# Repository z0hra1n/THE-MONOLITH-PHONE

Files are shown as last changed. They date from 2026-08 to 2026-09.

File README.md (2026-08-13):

# MONOLITH
bVXsz1786632561

Ahh, i finally get to yap about it.
This is MONOLITH. a phone, a brick , a portable computer, but most importantly, a MONOLITH.
The reason im calling it a monolith cuz its literally gonna be built like a shiny MONOLITH. especially because its outer body is inteded to be made from aluminum which acts as a passive heat sink and looks pretty cool.The design was heavily inspired by Nothing and Apple.

The pcb is quite complicated, and the design is pretty human.It was not easy to make as i am only 15, this is my second pcb, the schematic itself was very hard.The pcb ws harder.I got help from reddit and tomachie.com with the schematic so it was pretty easy to disagnose.But, when it came to me m,aking the pcb, after i was done connecting everything, the drc gave 2000 violations.I was scared, but turns out most of those were easy fixable in one or two clicks.I also did not keep in mind the manufacturing constraints, so i fixed the values, and most of the errors were gone.I was pleased.






Finally, i made the enclosure very minimalist and functional.The back has a plastic went to let out the rf and wifi/bt signals.
the rear camera physically rotates to become the selfie camera.



The specs are pretty nuts.It has the radxa nx5 16 gb ram and 256 emms variant.An oled with 120hz refresh rate, and a batter of about 120000 mah.Im not sure itll last much without optimisation tho.

Yeah! i hope it overtakes apple!

| Purpose | Component / Item | Qty | Cost (USD) | Distributor | Part Number |
|---|---|----:|---:|---|---|
| Decoupling | 10µF 25V X5R 0603 Capacitor | 10 | $1.46 | Digi-Key | GRM188R61E106MA73J |
| Bulk Decoupling | 22µF 16V 0603 Capacitor | 12 | $4.44 | Digi-Key | GMC10X5R226M16NTCT |
| Power Filtering | 1µF 25V X7R 0603 Capacitor | 10 | $0.52 | Digi-Key | TMK107B7105KA-T |
| Signal Filtering | 10nF 100V X7R Capacitor | 5 | $0.48 | Digi-Key | GCM188R72A103KA37D |
| Signal Filtering | 47nF 50V X7R Capacitor | 5 | $1.00 | Digi-Key | GCM188R71H473KA55D |
| Decoupling | 100nF 50V Y5V Capacitor | 5 | $0.48 | Digi-Key | CC0603ZRY5V9BB104 |
| Crystal Load | 18pF C0G Capacitor | 5 | $1.29 | Digi-Key | QSCP251Q180J1GV001T |
| Power Filtering | 4.7µF 25V X5R Capacitor | 5 | $1.15 | Digi-Key | GRM188R61E475KE11D |
| Pull-ups / General | 10kΩ 1% Resistor | 15 | $0.46 | Digi-Key | CRCW060310K0FKEA |
| Voltage Divider | 47kΩ 1% Resistor | 5 | $0.48 | Digi-Key | RC0603FR-0747KL |
| Feedback Divider | 255kΩ 1% Resistor | 5 | $0.48 | Digi-Key | ERJ-3EKF2553V |
| Feedback Divider | 180kΩ 5% Resistor | 5 | $0.48 | Digi-Key | RC0603JR-07180KL |
| Feedback Divider | 56kΩ 1% Resistor | 5 | $0.48 | Digi-Key | ERJ-3EKF5602V |
| Pull-ups | 2.2kΩ 1% Resistor | 10 | $0.24 | Digi-Key | RC0603FR-072K2L |
| USB Configuration | 5.1kΩ 1% Resistor | 5 | $0.53 | Digi-Key | RC0603FR-075K1L |
| Precision Divider | 29.8kΩ 0.1% Resistor | 5 | $0.53 | Digi-Key | RT0603BRD0729K8L |
| General Purpose | 12kΩ 1% Resistor | 5 | $0.48 | Digi-Key | RC0603FR-0712KL |
| Feedback Divider | 240kΩ 5% Resistor | 5 | $0.48 | Digi-Key | ERJ-3GEYJ244V |
| General Purpose | 1kΩ 1% Resistor | 5 | $0.48 | Digi-Key | CRCW06031K00FKEA |
| Compute Module Interface | 260-pin SODIMM Socket | 2 | $3.50 | Digi-Key | 2309407-1 |
| Display Interface | 22-pin FFC Connector | 2 | $4.91 | Digi-Key | FH12-22S-0.5SH(55) |
| Display Output | Micro HDMI Receptacle | 2 | $3.94 | Digi-Key | 0467651301 |
| USB Connectivity | USB Type-C Receptacle | 2 | $0.61 | Digi-Key | USB4970-00-A |
| Battery Charging | BQ25895 Li-Ion Charger IC | 2 | $6.42 | Digi-Key | BQ25895RTWR |
| Audio Output | SSM2518 Class-D Amplifier | 1 | $7.18 | Digi-Key | SSM2518CPZ |
| Input Protection | 6V TVS Diode | 2 | $0.92 | Digi-Key | SMAJ6.0CA |
| 5V Power Rail | TPS61088 10A Boost Converter | 2 | $5.24 | Digi-Key | TPS61088RHLR |
| USB Protection | USB ESD Protection IC | 5 | $5.64 | Digi-Key | TPD2EUSB30DRTR |
| RF Connection | U.FL (MHF1) Coax Cable | 1 | $2.04 | Digi-Key | CA-DKCA1-100L1-I0I0 |
| USB Expansion | USB2512B 2-Port USB Hub | 2 | $3.36 | Digi-Key | USB2512B-AEZG |
| Motion Sensing | BMI270 IMU | 1 | $4.04 | Digi-Key | BMI270 |
| Clock Source | 24MHz Crystal | 2 | $0.99 | Digi-Key | 535-10643-1 |
| User Input | Tactile Push Button | 5 | $1.82 | Digi-Key | SWT0005-015516SSAC |
| Power Stage | 2.2µH 15A Inductor | 2 | $2.81 | Digi-Key | MWSA1205S-2R2MT |
| Power Stage | 1µH 10A Inductor | 2 | $4.41 | Digi-Key | 74437349010 |
| 1.8V Rail | AP2112K 1.8V LDO | 2 | $0.52 | Digi-Key | AP2112K-1.8TRG1 |
| 3.3V Rail | TLV75533 3.3V LDO | 2 | $0.59 | Digi-Key | TLV75533PDQNR |
| Cellular Connectivity | LTE FPC Antenna | 1 | $2.81 | Digi-Key | AANI-FB-0173 |
| Display Cable | Micro HDMI to Mini HDMI Cable | 1 | $4.68 | Digi-Key | FIT0649 |
| USB Accessories | USB-A to Micro USB Cable | 2 | $3.02 | Digi-Key | DH-20M50055 |
| USB Accessories | USB-C to USB-C Cable | 1 | $4.46 | Digi-Key | 10165794-Z0100YBLF |
| Additional Decoupling | 100nF X7R Capacitor | 10 | $0.67 | Digi-Key | C0603C104K3RACTU |
| Thermal Management | Heat Sink Thermal Sticker | 1 | $1.43 | Digi-Key | 6308 |
| Assembly | Kapton Tape (10mm) | 1 | $2.78 | Digi-Key | KAPTON-TAPE10MM |
| Temperature Monitoring | 10kΩ NTC Thermistor | 2 | $1.88 | Digi-Key | B57861S0103F040 |
| Camera | 12MP IMX477P Camera Module | 1 | $59.99 | Arducam | B0517 |
| Miscellaneous | Batteries, BLE Module, Connectors | 4 | $290.47 | AliExpress | Various |
| PCB Manufacturing | PCB Fabrication + Engineering | 1 | $72.96 | PCB Fab | — |
| Portable Power | 20,000mAh Power Bank | 1 | $30.29 | Amazon | Duracell |
| Enclosure | CNC Aluminium Enclosure (Estimate) | 1 | $100.00 | Local Fabricator | — |
| **TOTAL** | | | **$649.81** | | |

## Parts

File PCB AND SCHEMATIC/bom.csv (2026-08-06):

Designator | Footprint | Quantity | Value | LCSC Part #
C1, C10, C14, C2, C23, C35 | 0603 | 6 | 0.1uf
C11 | 0603 | 1 | 10nf
C12, C39 | 0603 | 2 | 47nf
C13, C18, C19, C24, C4, C40, C7, C8, C9 | 0603 | 9 | 22uf
C15, C3, C37, C42, C6 | 0603 | 5 | 10uf
C16, C17, C20, C22, C29, C36, C5 | 0603 | 7 | 1uf
C21, C28, C33, C34 | 0603 | 4 | 100nf
C30, C31 | 0603 | 2 | 18pf
C41 | 0603 | 1 | 4.7uf
D1 | D_SMA_Handsoldering | 1 | SMAJ6.0CA
D3 | SOTFL35P100X50-3N | 1 | solder pads for rfp
D4 | SOTFL35P100X50-3N | 1 | solder pads for wifi/btp
D5 | SOTFL35P100X50-3N | 1 | TOUCHp
D6 | 0603 | 1 | LED
F1 | FUSE_MF-SM185_BRN | 1 | MF-SM250-2
J1 | 260 | 1 | 260 SODIMM
J10 | HDMI_Micro-D_Molex_46765-2xxx | 1 | HDMI_A
J12 | USB 3.0 | 1 | USB4115-03-C_REVA
J13 | TOUCH | 1 | TOUCH
J14 | RF | 1 | solder pads for rf
J15 | WIFI_BT | 1 | solder pads for wifi/bt
J2 | Hirose_FH12-22S-0.5SH_1x22-1MP_P0.50mm_Horizontal | 1 | Conn_02x11_Odd_Even
J5 | battery | 1 | Battery
J6, J7 | JST_PH_S2B-PH-K_1x02_P2.00mm_Horizontal | 2 | speaker 1
L1 | INDUCTOR | 1 | 2.2uH
L2 | WE-LHMI_7050 | 1 | 74437349010
R1, R15, R16, R17, R19, R2, R20, R21, R22, R3, R32 | 0603 | 11 | 10k
R10, R6 | 0603 | 2 | 180k
R11, R28, R29 | 0603 | 3 | 5.1k
R12 | 0603 | 1 | 29.87k
R13, R14, R23, R24, R27, R9 | 0603 | 6 | 2.2k
R18 | 0603 | 1 | 12k
R25 | 0603 | 1 | 240k
R26 | 0603 | 1 | 1k
R30, R31, R7, R8 | 0603 | 4 | 56k
R4 | 0603 | 1 | 47k
R5 | 0603 | 1 | 255k
S1, S2, S3 | SIDESWITCH | 3 | SIDESWITCH
U1 | TLV | 1 | TLV75533PDQNR
U2 | DGS10 | 1 | TS5A23157DGSR
U3 | TPS | 1 | TPS61088RHLR
U4 | SOT-23-5 | 1 | AP2112K-1.8
U5 | SSM | 1 | SSM2518CPZ
U6 | Texas_RTW_WQFN-24-1EP_4x4mm_P0.5mm_EP2.7x2.7mm_ThermalVias | 1 | BQ25895RTW
U7 | HUB | 1 | USB2422/MJ
U8 | BMI | 1 | BMI270
Y1 | Crystal_SMD_5032-2Pin_5.0x3.2mm_HandSoldering | 1 | 24MHZ

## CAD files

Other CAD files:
Concept model/PHONE.blend

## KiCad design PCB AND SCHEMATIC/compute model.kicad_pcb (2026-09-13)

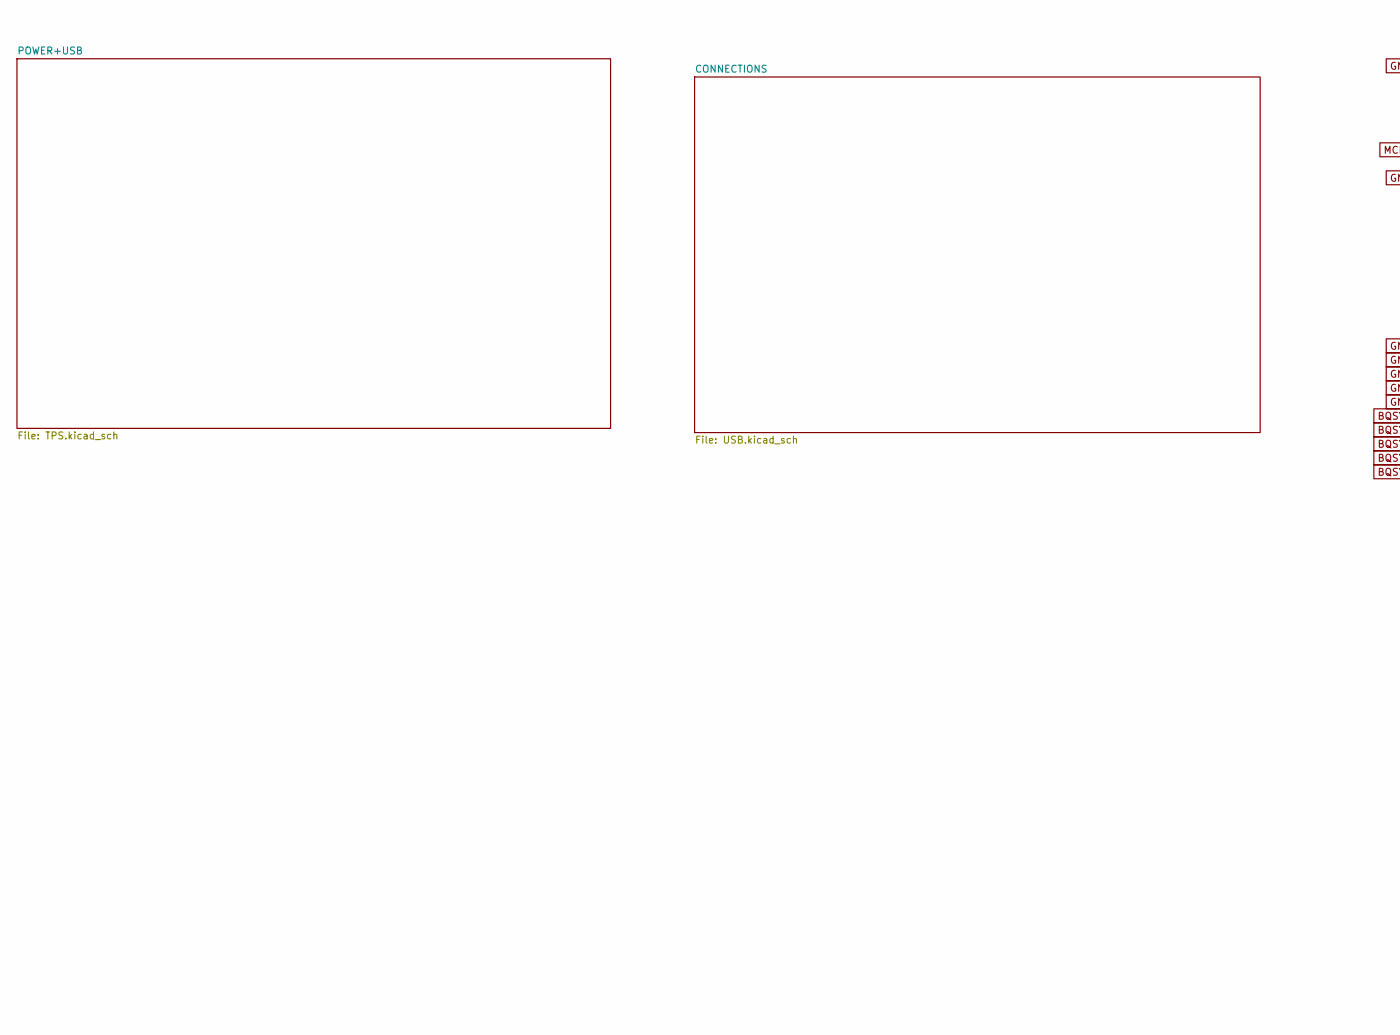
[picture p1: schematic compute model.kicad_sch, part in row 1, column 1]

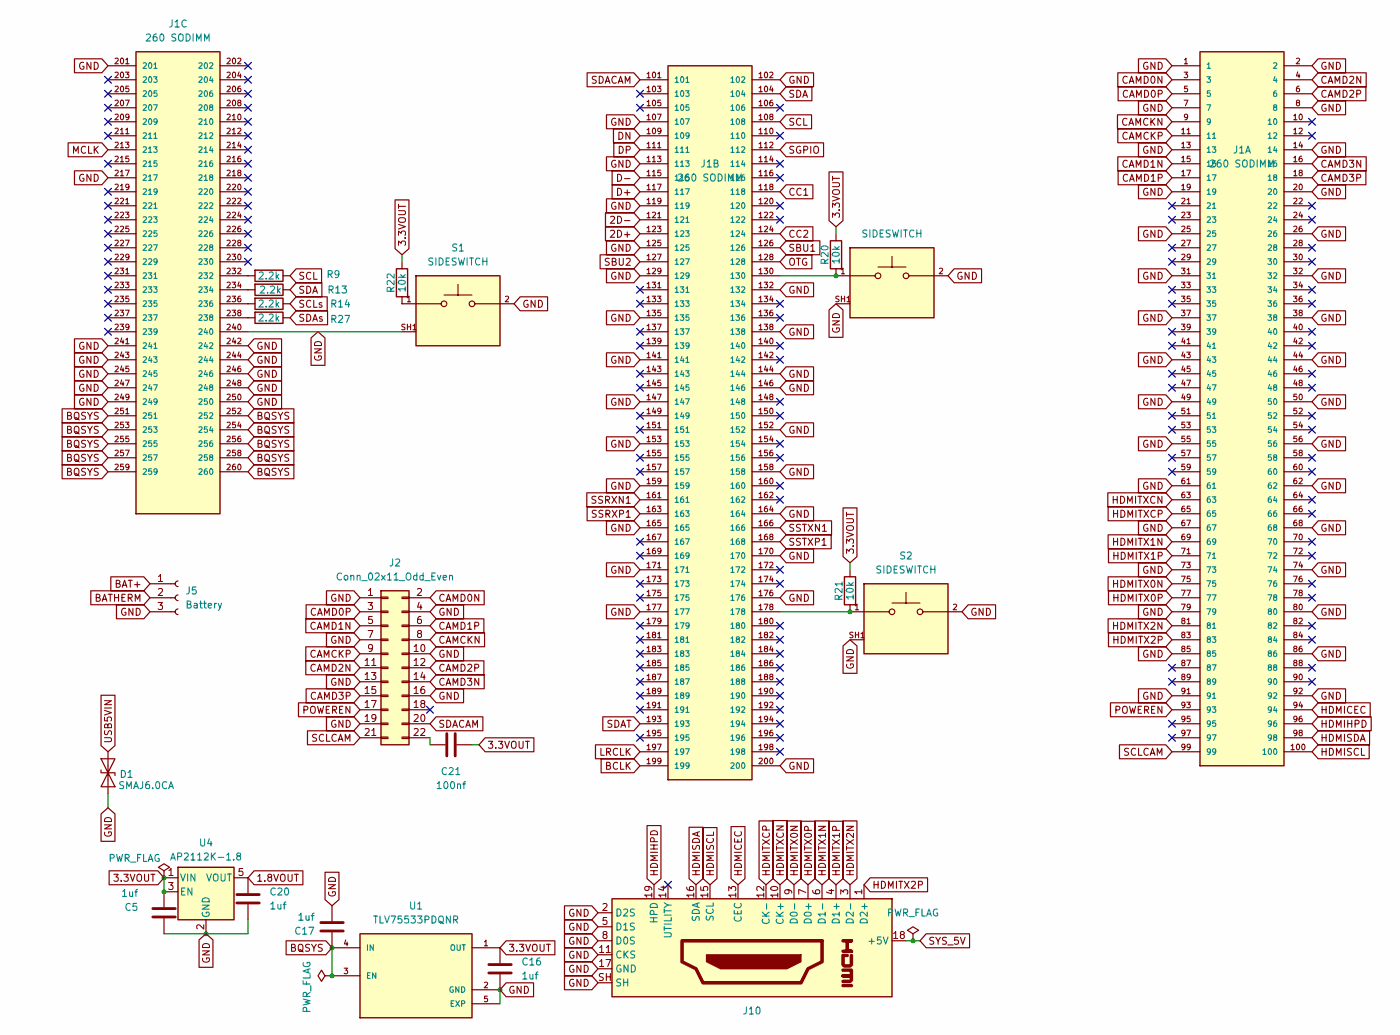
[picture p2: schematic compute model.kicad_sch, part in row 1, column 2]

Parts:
C5, C16, C17, C20: 1uf; C_0603_1608Metric_Pad1.08x0.95mm_HandSolder
C21: 100nf; C_0603_1608Metric_Pad1.08x0.95mm_HandSolder
D1: SMAJ6.0CA; D_SMA_Handsoldering
J1: 260 SODIMM; 260; PARTREV 5
J2: Conn_02x11_Odd_Even; Hirose_FH12-22S-0.5SH_1x22-1MP_P0.50mm_Horizontal
J5: Battery; battery
J10: HDMI_A; HDMI_Micro-D_Molex_46765-2xxx
R9, R13, R14, R27: 2.2k; R_0603_1608Metric_Pad0.98x0.95mm_HandSolder
R20, R21, R22: 10k; R_0603_1608Metric_Pad0.98x0.95mm_HandSolder
S1, S2, S3: SIDESWITCH
U1: TLV75533PDQNR; TLV
U4: AP2112K-1.8; SOT-23-5

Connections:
1.8VOUT: C20.1, U4.5 (VOUT); also elsewhere on the board
2D+: J1.123; also elsewhere on the board
2D-: J1.121; also elsewhere on the board
3.3VOUT: C5.2, C16.1, C21.1, R20.1, R21.1, R22.1, U1.1 (OUT), U4.1 (VIN), U4.3 (EN); also elsewhere on the board
BAT+: J5.1; also elsewhere on the board
BATHERM: J5.2; also elsewhere on the board
BCLK: J1.199; also elsewhere on the board
BQSYS: C17.1, J1.251, J1.252, J1.253, J1.254, J1.255, J1.256, J1.257, J1.258, J1.259, J1.260, U1.3 (EN), U1.4 (IN); also elsewhere on the board
CAMCKN: J1.9, J2.8
CAMCKP: J1.11, J2.9
CAMD0N: J1.3, J2.2
CAMD0P: J1.5, J2.3
CAMD1N: J1.15, J2.5
CAMD1P: J1.17, J2.6
CAMD2N: J1.4, J2.11
CAMD2P: J1.6, J2.12
CAMD3N: J1.16, J2.14
CAMD3P: J1.18, J2.15
CC1: J1.118; also elsewhere on the board
CC2: J1.124; also elsewhere on the board
D+: J1.117; also elsewhere on the board
D-: J1.115; also elsewhere on the board
DN: J1.109; also elsewhere on the board
DP: J1.111; also elsewhere on the board
GND: C5.1, C16.2, C17.2, C20.2, D1.1 (A1), J1.1, J1.2, J1.7, J1.8, J1.13, J1.14, J1.19, J1.20, J1.25, J1.26, J1.31, J1.32, J1.37, J1.38, J1.43, J1.44, J1.49, J1.50, J1.55, J1.56, J1.61, J1.62, J1.67, J1.68, J1.73, J1.74, J1.79, J1.80, J1.85, J1.86, J1.91, J1.92, J1.102, J1.107, J1.113, J1.119, J1.125, J1.129, J1.132, J1.135, J1.138, J1.141, J1.144, J1.146, J1.147, J1.152, J1.153, J1.158, J1.159, J1.164, J1.165, J1.170, J1.171, J1.176, J1.177, J1.200, J1.201, J1.217, J1.240, J1.241, J1.242, J1.243, J1.244, J1.245, J1.246, J1.247, J1.248, J1.249, J1.250, J2.1, J2.4, J2.7, J2.10, J2.13, J2.16, J2.19, J5.3, J10.2 (D2S), J10.5 (D1S), J10.8 (D0S), J10.11 (CKS), J10.17 (GND), J10.SH, S1.2, S1.SH1, S2.2, S2.SH1, S3.2, S3.SH1, U1.2 (GND), U1.5 (EXP), U4.2 (GND); also elsewhere on the board
HDMICEC: J1.94, J10.13 (CEC)
HDMIHPD: J1.96, J10.19 (HPD)
HDMISCL: J1.100, J10.15 (SCL)
HDMISDA: J1.98, J10.16 (SDA)
HDMITX0N: J1.75, J10.9 (D0-)
HDMITX0P: J1.77, J10.7 (D0+)
HDMITX1N: J1.69, J10.6 (D1-)
HDMITX1P: J1.71, J10.4 (D1+)
HDMITX2N: J1.81, J10.3 (D2-)
HDMITX2P: J1.83, J10.1 (D2+)
HDMITXCN: J1.63, J10.10 (CK+)
HDMITXCP: J1.65, J10.12 (CK-)
LRCLK: J1.197; also elsewhere on the board
MCLK: J1.213; also elsewhere on the board
unnamed: J1.130, R20.2, S3.1
unnamed: J1.178, R21.2, S2.1
unnamed: J1.232, R9.2
unnamed: J1.234, R13.2
unnamed: J1.236, R14.2
unnamed: J1.238, R27.2
unnamed: C21.2, J2.22
unnamed: R22.2, S1.1
OTG: J1.128; also elsewhere on the board
POWEREN: J1.93, J2.17
SBU1: J1.126; also elsewhere on the board
SBU2: J1.127; also elsewhere on the board
SCL: J1.108, R9.1; also elsewhere on the board
SCLs: R14.1; also elsewhere on the board
SDA: J1.104, R13.1; also elsewhere on the board
SDAT: J1.193; also elsewhere on the board
SDAs: R27.1; also elsewhere on the board
SGPIO: J1.112; also elsewhere on the board
SSRXN1: J1.161; also elsewhere on the board
SSRXP1: J1.163; also elsewhere on the board
SSTXN1: J1.166; also elsewhere on the board
SSTXP1: J1.168; also elsewhere on the board
SYS_5V: J10.18 (+5V); also elsewhere on the board
USB5VIN: D1.2 (A2); also elsewhere on the board

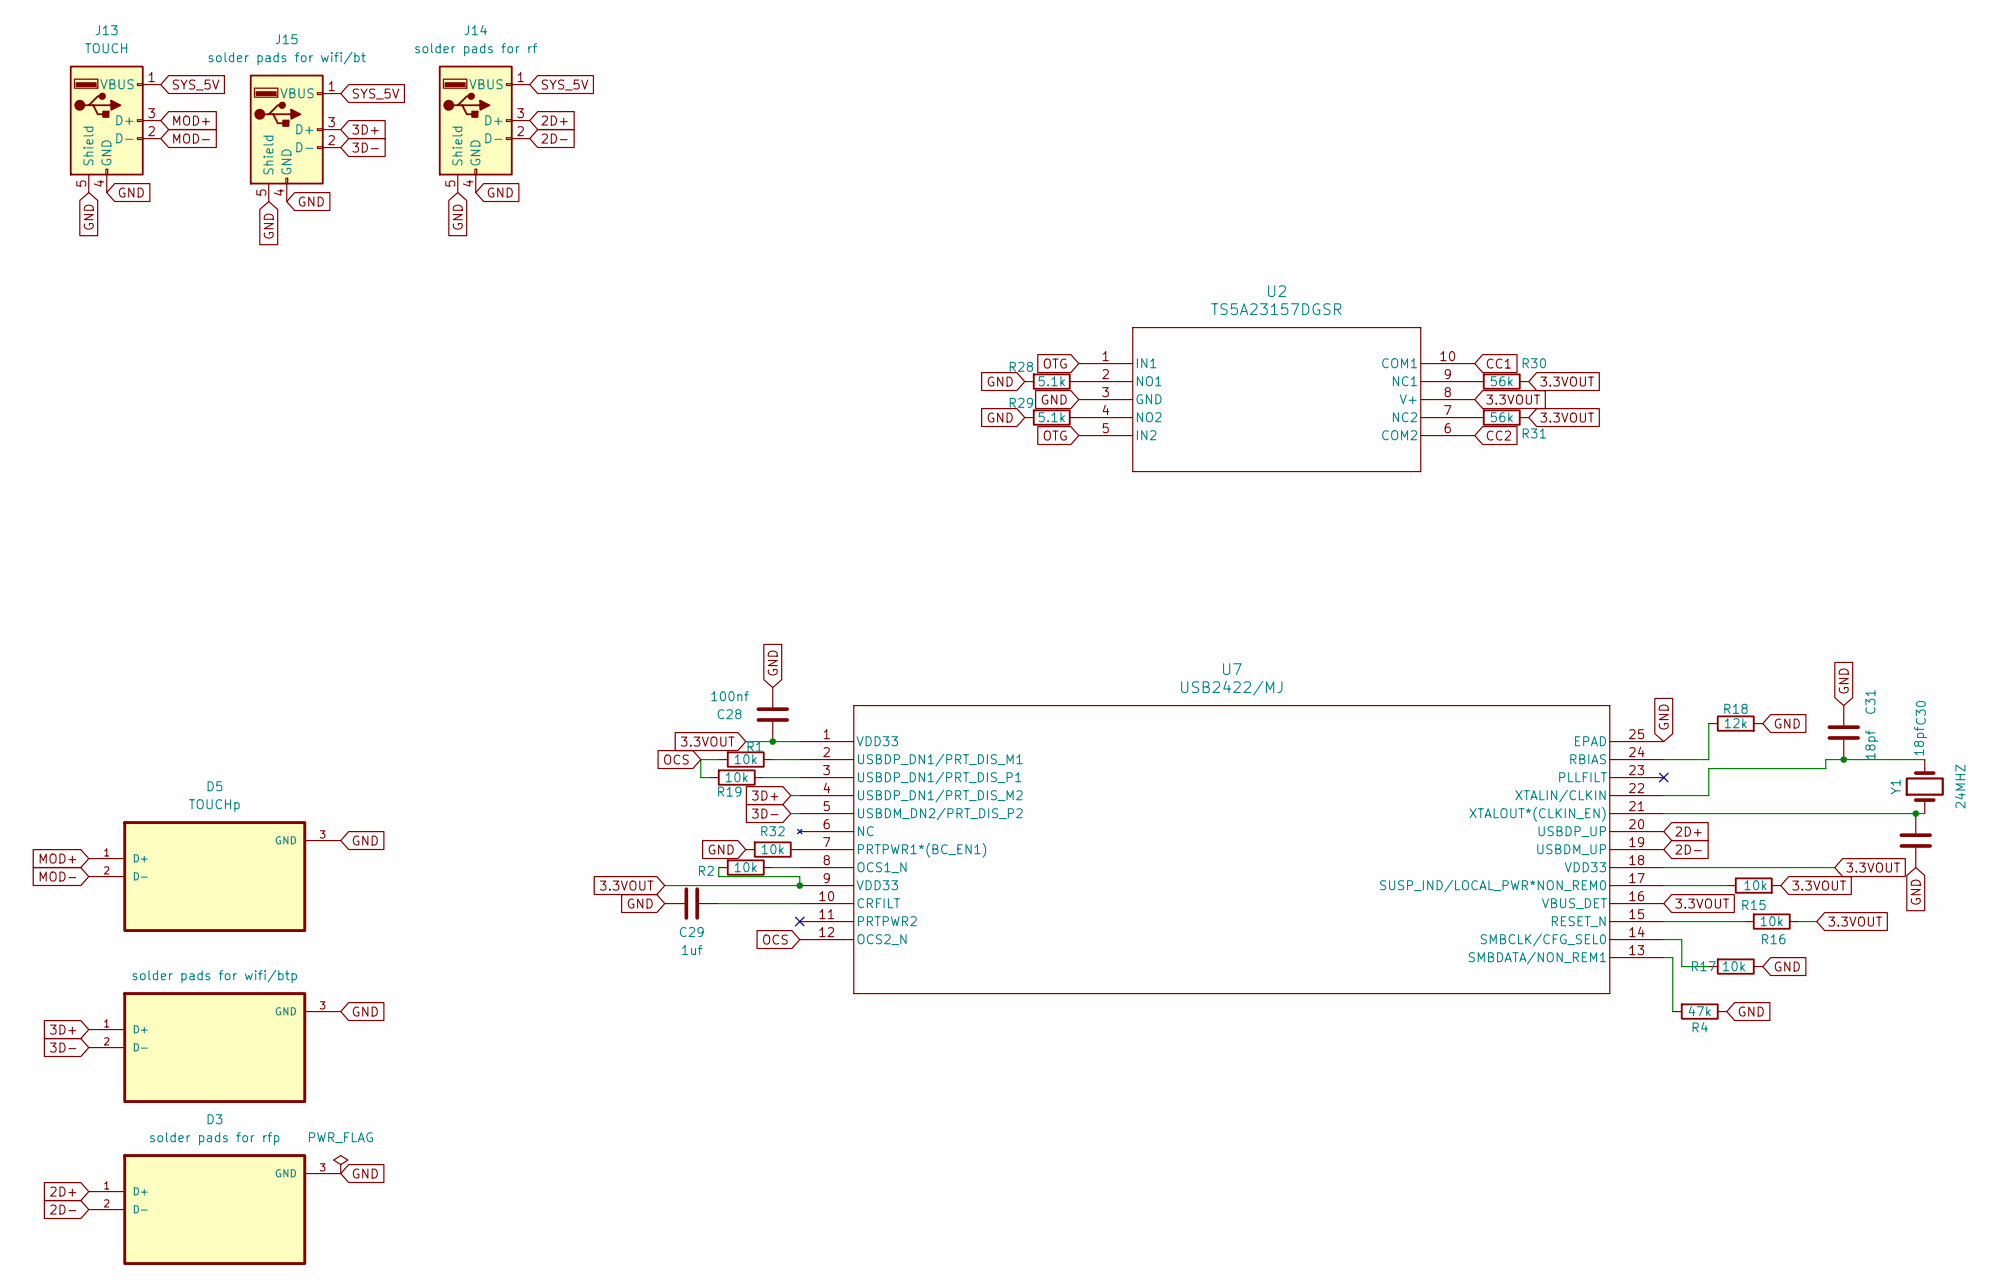
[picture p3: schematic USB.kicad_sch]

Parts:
C28: 100nf; C_0603_1608Metric_Pad1.08x0.95mm_HandSolder
C29: 1uf; C_0603_1608Metric_Pad1.08x0.95mm_HandSolder
C30, C31: 18pf; C_0603_1608Metric_Pad1.08x0.95mm_HandSolder
D3: solder pads for rfp; SOTFL35P100X50-3N; DigiKey_Part_Number 296-25509-1-ND
D4: solder pads for wifi/btp; SOTFL35P100X50-3N; DigiKey_Part_Number 296-25509-1-ND
D5: TOUCHp; SOTFL35P100X50-3N; DigiKey_Part_Number 296-25509-1-ND
J13: TOUCH
J14: solder pads for rf; RF
J15: solder pads for wifi/bt; WIFI_BT
R1, R2, R15, R16, R17, R19, R32: 10k; R_0603_1608Metric_Pad0.98x0.95mm_HandSolder
R4: 47k; R_0603_1608Metric_Pad0.98x0.95mm_HandSolder
R18: 12k; R_0603_1608Metric_Pad0.98x0.95mm_HandSolder
R28, R29: 5.1k; R_0603_1608Metric_Pad0.98x0.95mm_HandSolder
R30, R31: 56k; R_0603_1608Metric_Pad0.98x0.95mm_HandSolder
U2: TS5A23157DGSR; DGS10
U7: USB2422/MJ; HUB
Y1: 24MHZ; Crystal_SMD_5032-2Pin_5.0x3.2mm_HandSoldering

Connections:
2D+: D3.1 (D+), J14.3 (D+), U7.20 (USBDP_UP); also elsewhere on the board
2D-: D3.2 (D-), J14.2 (D-), U7.19 (USBDM_UP); also elsewhere on the board
3.3VOUT: C28.2, R2.2, R15.2, R16.1, R30.1, R31.1, U2.8 (V+), U7.1 (VDD33), U7.9 (VDD33), U7.16 (VBUS_DET), U7.18 (VDD33); also elsewhere on the board
3D+: D4.1 (D+), J15.3 (D+), U7.4 (USBDP_DN1/PRT_DIS_M2)
3D-: D4.2 (D-), J15.2 (D-), U7.5 (USBDM_DN2/PRT_DIS_P2)
CC1: U2.10 (COM1); also elsewhere on the board
CC2: U2.6 (COM2); also elsewhere on the board
GND: C28.1, C29.2, C30.2, C31.1, D3.3 (GND), D4.3 (GND), D5.3 (GND), J13.4 (GND), J13.5 (Shield), J14.4 (GND), J14.5 (Shield), J15.4 (GND), J15.5 (Shield), R4.1, R17.1, R18.2, R28.2, R29.2, R32.2, U2.3 (GND), U7.25 (EPAD); also elsewhere on the board
MOD+: D5.1 (D+), J13.3 (D+)
MOD-: D5.2 (D-), J13.2 (D-)
unnamed: R30.2, U2.9 (NC1)
unnamed: R31.2, U2.7 (NC2)
unnamed: R28.1, U2.2 (NO1)
unnamed: R29.1, U2.4 (NO2)
unnamed: C29.1, U7.10 (CRFILT)
unnamed: R2.1, U7.8 (OCS1_N)
unnamed: R32.1, U7.7 (PRTPWR1*(BC_EN1))
unnamed: R18.1, U7.24 (RBIAS)
unnamed: R16.2, U7.15 (RESET_N)
unnamed: R17.2, U7.14 (SMBCLK/CFG_SEL0)
unnamed: R4.2, U7.13 (SMBDATA/NON_REM1)
unnamed: R15.1, U7.17 (SUSP_IND/LOCAL_PWR*NON_REM0)
unnamed: R1.1, U7.2 (USBDP_DN1/PRT_DIS_M1)
unnamed: R19.1, U7.3 (USBDP_DN1/PRT_DIS_P1)
unnamed: C31.2, U7.22 (XTALIN/CLKIN), Y1.2
unnamed: C30.1, U7.21 (XTALOUT*(CLKIN_EN)), Y1.1
OCS: R1.2, R19.2, U7.12 (OCS2_N)
OTG: U2.1 (IN1), U2.5 (IN2); also elsewhere on the board
SYS_5V: J13.1 (VBUS), J14.1 (VBUS), J15.1 (VBUS); also elsewhere on the board

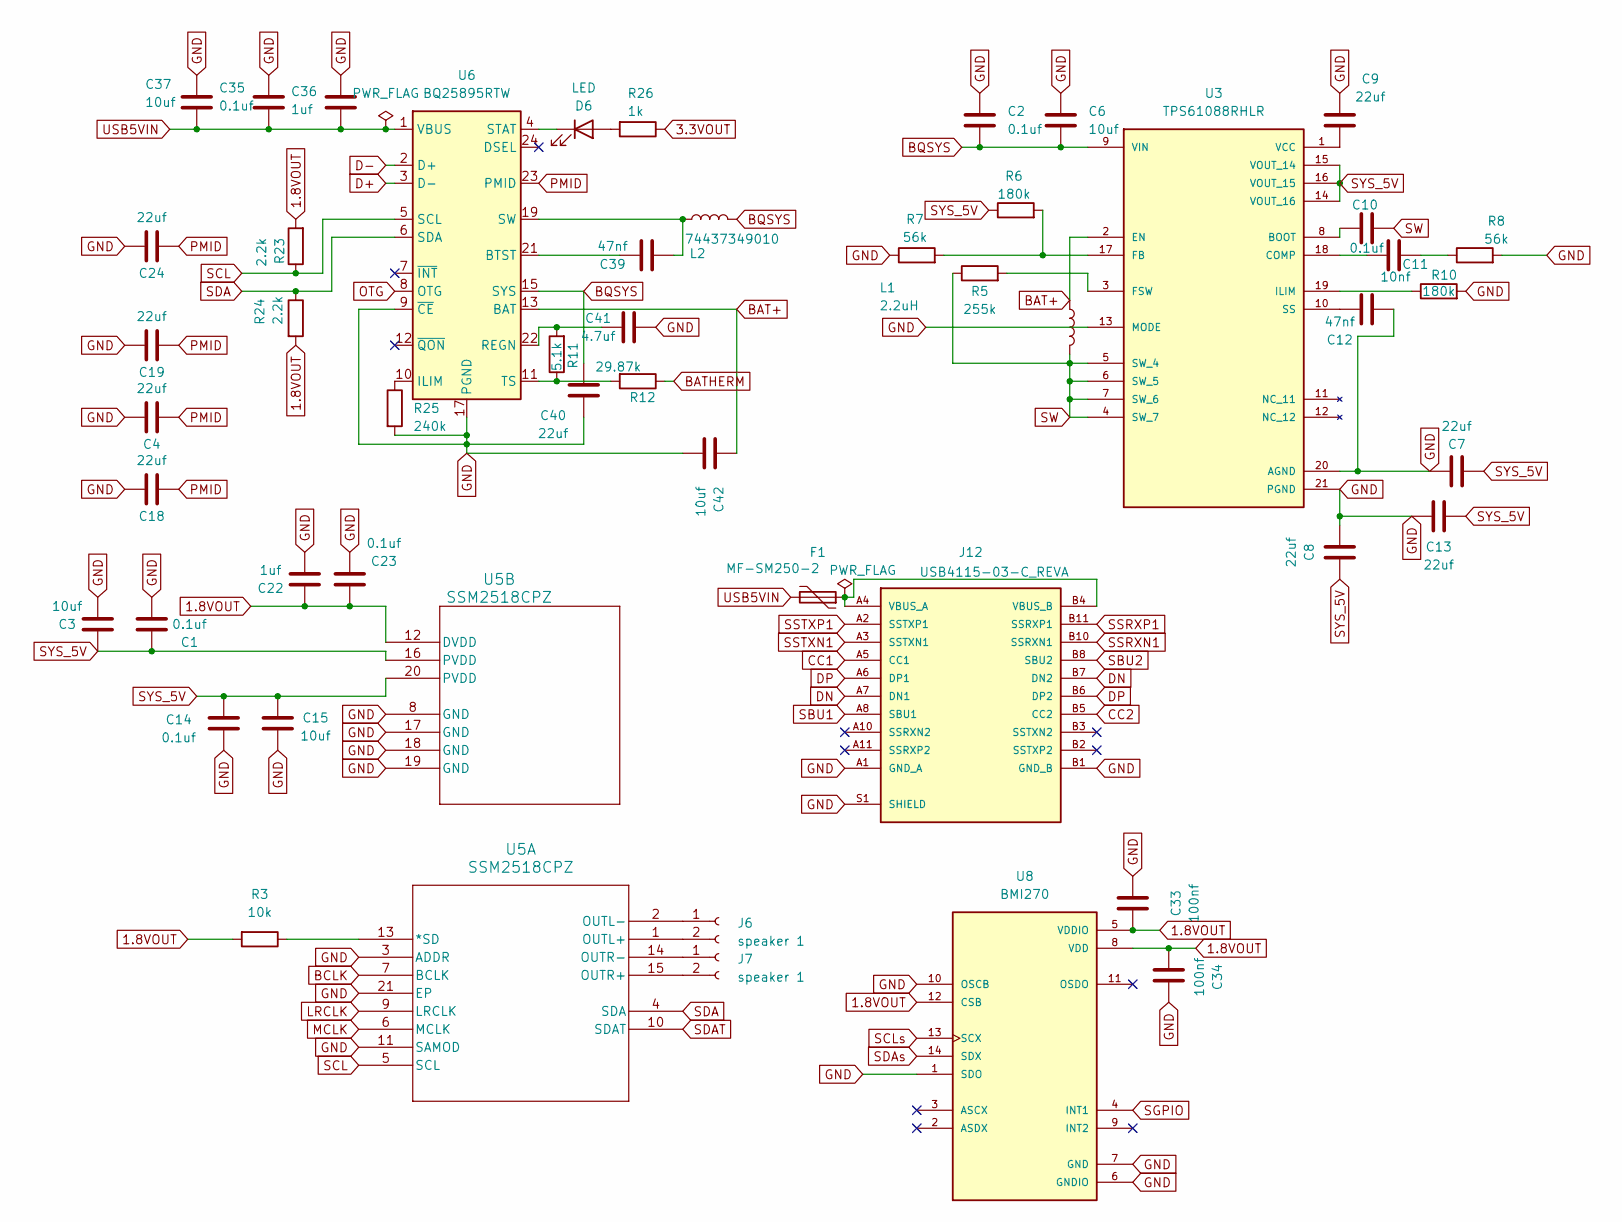
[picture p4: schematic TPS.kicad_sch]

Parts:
C1, C2, C10, C14, C23, C35: 0.1uf; C_0603_1608Metric_Pad1.08x0.95mm_HandSolder
C3, C6, C15, C37, C42: 10uf; C_0603_1608Metric_Pad1.08x0.95mm_HandSolder
C4, C7, C8, C9, C13, C18, C19, C24, C40: 22uf; C_0603_1608Metric_Pad1.08x0.95mm_HandSolder
C11: 10nf; C_0603_1608Metric_Pad1.08x0.95mm_HandSolder
C12, C39: 47nf; C_0603_1608Metric_Pad1.08x0.95mm_HandSolder
C22, C36: 1uf; C_0603_1608Metric_Pad1.08x0.95mm_HandSolder
C33, C34: 100nf; C_0603_1608Metric_Pad1.08x0.95mm_HandSolder
C41: 4.7uf; C_0603_1608Metric_Pad1.08x0.95mm_HandSolder
D6: LED; LED_0603_1608Metric_Pad1.05x0.95mm_HandSolder
F1: MF-SM250-2; FUSE_MF-SM185_BRN
J6, J7: speaker 1; JST_PH_S2B-PH-K_1x02_P2.00mm_Horizontal
J12: USB4115-03-C_REVA; USB 3.0; PARTREV A
L1: 2.2uH; INDUCTOR
L2: 74437349010; D_SOD-323
R3: 10k; R_0603_1608Metric_Pad0.98x0.95mm_HandSolder
R5: 255k; R_0603_1608Metric_Pad0.98x0.95mm_HandSolder
R6, R10: 180k; R_0603_1608Metric_Pad0.98x0.95mm_HandSolder
R7, R8: 56k; R_0603_1608Metric_Pad0.98x0.95mm_HandSolder
R11: 5.1k; R_0603_1608Metric_Pad0.98x0.95mm_HandSolder
R12: 29.87k; R_0603_1608Metric_Pad0.98x0.95mm_HandSolder
R23, R24: 2.2k; R_0603_1608Metric_Pad0.98x0.95mm_HandSolder
R25: 240k; R_0603_1608Metric_Pad0.98x0.95mm_HandSolder
R26: 1k; R_0603_1608Metric_Pad0.98x0.95mm_HandSolder
U3: TPS61088RHLR; TPS
U5: SSM2518CPZ; SSM
U6: BQ25895RTW; Texas_RTW_WQFN-24-1EP_4x4mm_P0.5mm_EP2.7x2.7mm_ThermalVias
U8: BMI270; BMI; DigiKey_Part_Number 828-1091-1-ND

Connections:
1.8VOUT: C22.2, C23.2, C33.2, C34.2, R3.2, R23.2, R24.2, U5.12 (DVDD), U8.5 (VDDIO), U8.8 (VDD), U8.12 (CSB); also elsewhere on the board
3.3VOUT: R26.1; also elsewhere on the board
BAT+: C42.1, L1.1, U3.2 (EN), U6.13 (BAT), U6.14 (BAT); also elsewhere on the board
BATHERM: R12.1; also elsewhere on the board
BCLK: U5.7 (BCLK); also elsewhere on the board
BQSYS: C2.2, C6.2, C40.2, L2.2, U3.9 (VIN), U6.15 (SYS), U6.16 (SYS); also elsewhere on the board
CC1: J12.A5 (CC1); also elsewhere on the board
CC2: J12.B5 (CC2); also elsewhere on the board
D+: U6.3 (D-); also elsewhere on the board
D-: U6.2 (D+); also elsewhere on the board
DN: J12.A7 (DN1), J12.B7 (DN2); also elsewhere on the board
DP: J12.A6 (DP1), J12.B6 (DP2); also elsewhere on the board
GND: C1.1, C2.1, C3.1, C4.2, C6.1, C7.1, C8.2, C9.2, C12.2, C13.2, C14.1, C15.1, C18.2, C19.2, C22.1, C23.1, C24.2, C33.1, C34.1, C35.1, C36.1, C37.1, C40.1, C41.2, C42.2, J12.A1 (GND_A), J12.B1 (GND_B), J12.S1 (SHIELD), R7.1, R8.2, R10.2, R25.2, U3.13 (MODE), U3.20 (AGND), U3.21 (PGND), U3.23, U3.24, U3.25, U3.26, U3.27, U3.28, U3.29, U3.gnd, U5.3 (ADDR), U5.8 (GND), U5.11 (SAMOD), U5.17 (GND), U5.18 (GND), U5.19 (GND), U5.21 (EP), U6.9 (~CE), U6.17 (PGND), U6.18 (PGND), U6.25 (PGND), U8.1 (SDO), U8.6 (GNDIO), U8.7 (GND), U8.10 (OSCB); also elsewhere on the board
LRCLK: U5.9 (LRCLK); also elsewhere on the board
MCLK: U5.6 (MCLK); also elsewhere on the board
unnamed: C11.2, R8.1
unnamed: C39.1, L2.1, U6.19 (SW), U6.20 (SW)
unnamed: D6.2 (A), R26.2
unnamed: D6.1 (K), U6.4 (STAT)
unnamed: J6.1, U5.2 (OUTL-)
unnamed: J6.2, U5.1 (OUTL+)
unnamed: J7.1, U5.14 (OUTR-)
unnamed: J7.2, U5.15 (OUTR+)
unnamed: F1.1, J12.A4 (VBUS_A), J12.B4 (VBUS_B)
unnamed: C10.1, U3.8 (BOOT)
unnamed: C11.1, U3.18 (COMP)
unnamed: R6.2, R7.2, U3.17 (FB)
unnamed: R5.2, U3.3 (FSW)
unnamed: R10.1, U3.19 (ILIM)
unnamed: C12.1, U3.10 (SS)
unnamed: C9.1, U3.1 (VCC)
unnamed: R3.1, U5.13 (*SD)
unnamed: C39.2, U6.21 (BTST)
unnamed: R25.1, U6.10 (ILIM)
unnamed: C41.1, R11.2, U6.22 (REGN)
unnamed: R11.1, R12.2, U6.11 (TS)
OTG: U6.8 (OTG); also elsewhere on the board
PMID: C4.1, C18.1, C19.1, C24.1, U6.23 (PMID)
SBU1: J12.A8 (SBU1); also elsewhere on the board
SBU2: J12.B8 (SBU2); also elsewhere on the board
SCL: R23.1, U5.5 (SCL), U6.5 (SCL); also elsewhere on the board
SCLs: U8.13 (SCX); also elsewhere on the board
SDA: R24.1, U5.4 (SDA), U6.6 (SDA); also elsewhere on the board
SDAT: U5.10 (SDAT); also elsewhere on the board
SDAs: U8.14 (SDX); also elsewhere on the board
SGPIO: U8.4 (INT1); also elsewhere on the board
SSRXN1: J12.B10 (SSRXN1); also elsewhere on the board
SSRXP1: J12.B11 (SSRXP1); also elsewhere on the board
SSTXN1: J12.A3 (SSTXN1); also elsewhere on the board
SSTXP1: J12.A2 (SSTXP1); also elsewhere on the board
SW: C10.2, L1.2, R5.1, U3.4 (SW_7), U3.5 (SW_4), U3.6 (SW_5), U3.7 (SW_6)
SYS_5V: C1.2, C3.2, C7.2, C8.1, C13.1, C14.2, C15.2, R6.1, U3.14 (VOUT_16), U3.15 (VOUT_14), U3.16 (VOUT_15), U5.16 (PVDD), U5.20 (PVDD); also elsewhere on the board
USB5VIN: C35.2, C36.2, C37.2, F1.2, U6.1 (VBUS); also elsewhere on the board

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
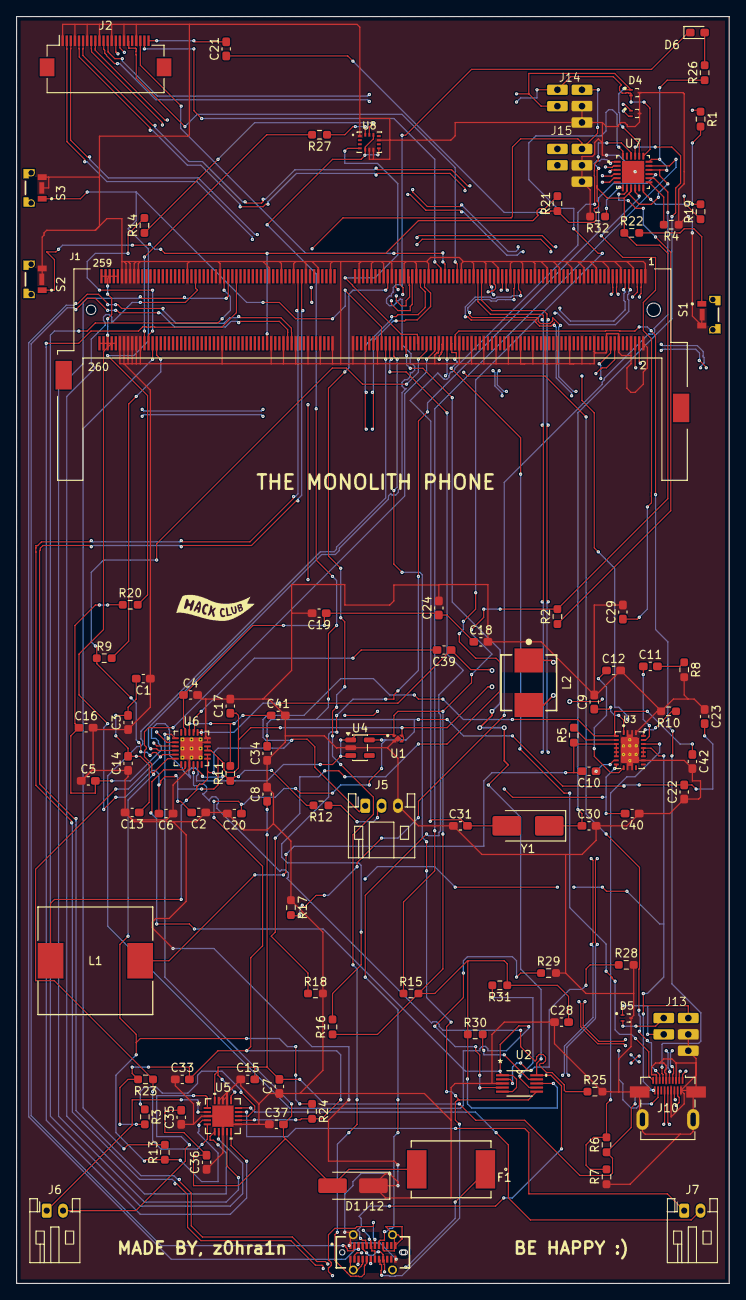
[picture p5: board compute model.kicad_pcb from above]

Board: 4 copper layers, 87.1 x 154.9 mm, 99 parts (0 on the bottom side), 109 nets.
